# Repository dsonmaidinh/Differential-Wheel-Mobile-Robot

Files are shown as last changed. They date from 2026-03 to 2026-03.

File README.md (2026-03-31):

# DMRobot

Demo DMRobot

`DMRobot` là dự án điều khiển robot di động với mô hình **ESP32-S3 + STM32F103**, dùng **WebSocket/WiFi** để giao tiếp giữa app web và STM32 qua ESP32.

## Tổng quan

Dự án gồm hai phần chính:

- `firmware/esp`: firmware cho ESP32-S3 DevKitM-1 sử dụng PlatformIO và Arduino.
- `firmware/stm`: firmware cho STM32F103RCT6 với bộ xử lý điều khiển robot.

Ngoài ra, dự án còn có:

- `hardware/`: tài liệu PCB, sơ đồ mạch, file thiết kế board.
- `software/`: công cụ Python, GUI và script hỗ trợ kiểm tra/phân tích.
- `docs/`: ảnh và GIF minh họa app/robot.

## Tính năng chính

- Mô-đun ESP32-S3 làm gateway WiFi, chạy web server và WebSocket.
- Cầu nối UART giữa ESP32 và STM32 để gửi/nhận lệnh điều khiển.
- Hỗ trợ lệnh: `STOP`, `RUN`, `RETURN_HOME`, `SET_TRAJECTORY`, `SET_PATH`, `STATUS`.
- Giao tiếp JSON qua WebSocket để điều khiển và cấu hình từ app web.
- Chế độ WiFi AP với SSID mặc định `DMRobot_Net` và password `12345678`.
- Chế độ WiFi STA có thể cấu hình WiFi nhà sẵn trong `firmware/esp/src/main.cpp`.
- Giám sát trạng thái pin và trạng thái kết nối mạng.

## Giao diện

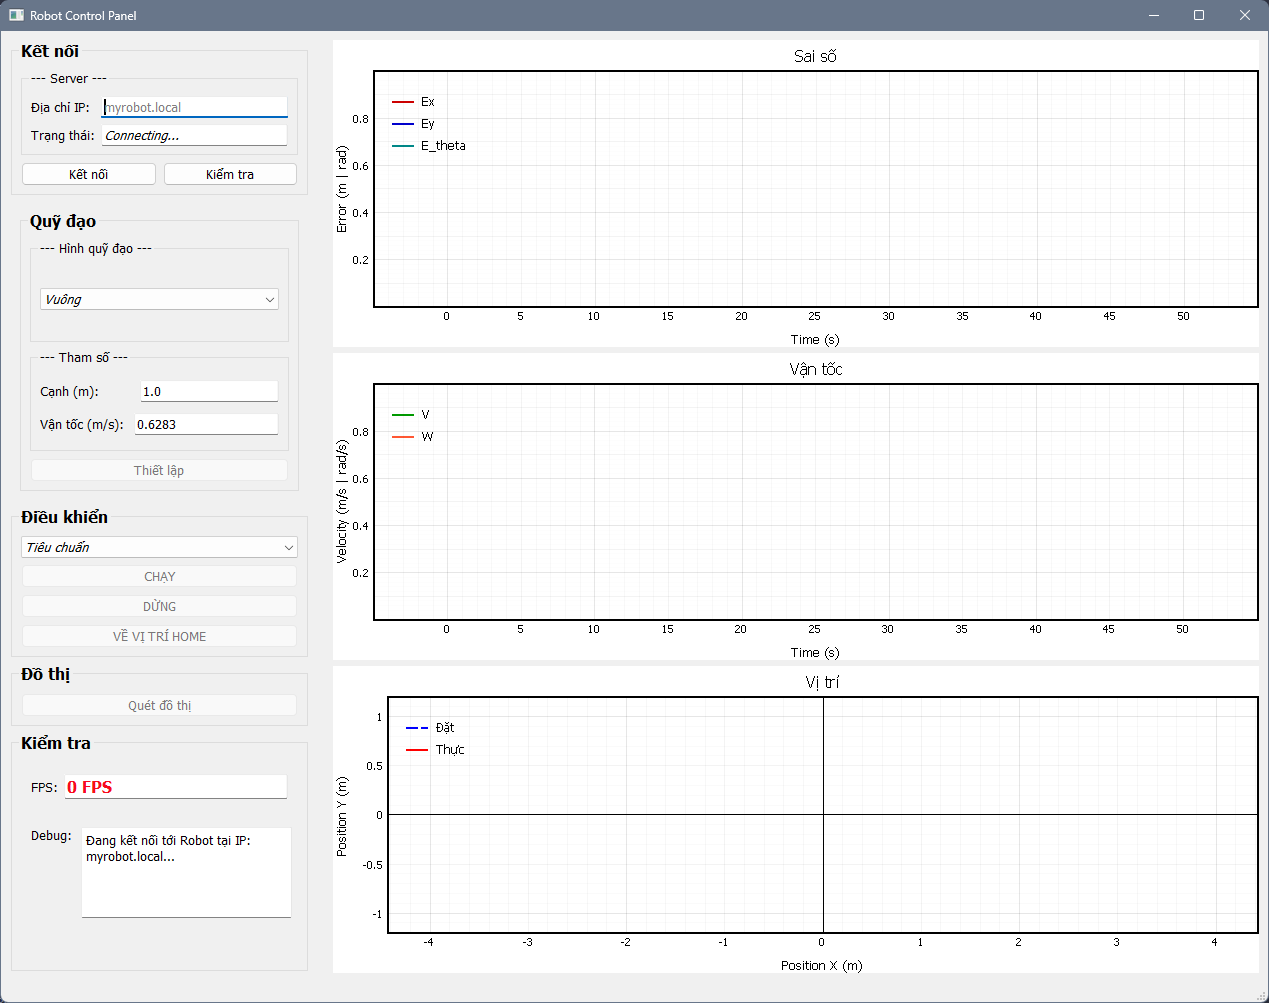
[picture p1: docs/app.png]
App DMRobot


## Cấu trúc thư mục

- `docs/`
  - `app.png`: ảnh giao diện ứng dụng.
  - `DMRobot.gif`: GIF demo.
- `firmware/esp/`
  - `platformio.ini`: cấu hình PlatformIO cho ESP32-S3.
  - `src/main.cpp`: mã nguồn chính điều khiển WiFi, WebSocket, UART.
- `firmware/stm/`
  - STM32F103 firmware và mã nguồn điều khiển robot.
- `hardware/`
  - Thiết kế PCB, sơ đồ, file xuất Gerber và các tài liệu phần cứng.
- `software/`
  - Script Python và phần mềm hỗ trợ.

## Cài đặt và chạy

1. Mở `firmware/esp` với PlatformIO.
2. Chọn environment: `esp32-s3-devkitm-1`.
3. Kết nối ESP32-S3 và build/upload firmware.
4. Mở Serial Monitor với tốc độ `115200`.
5. Kết nối WiFi tới `DMRobot_Net` hoặc cấu hình WiFi STA trong `firmware/esp/src/main.cpp`.
6. Truy cập trang web điều khiển hoặc `myrobot.local` nếu mDNS hoạt động.

## Tùy chỉnh

- Thay đổi SSID/AP và mật khẩu trong `firmware/esp/src/main.cpp`:
  - `ROBOT_WIFI_SSID`
  - `ROBOT_WIFI_PASSWORD`
  - `MY_WIFI_SSID`
  - `MY_WIFI_PASSWORD`
- Điều chỉnh tốc độ UART và chân RX/TX cho ESP32-S3 cũng nằm trong `firmware/esp/src/main.cpp`.

## Ghi chú

- ESP32-S3 kết nối tới STM32 qua UART trên chân `RX_PIN = 40` và `TX_PIN = 39`.
- Firmware STM32 nằm trong `firmware/stm` và cần STM32CubeIDE hoặc tool tương thích để build.

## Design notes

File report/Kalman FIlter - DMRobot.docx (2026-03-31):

# CHƯƠNG 1: Lý thuyết

## 1.1. Phương trình EKF Tổng quát và Giải phẫu thành phần

Một hệ thống tự hành luôn được mô tả bằng 2 phương trình phi tuyến cơ bản:

### 1.1.1. Phương trình chuyển trạng thái (Kinematic Model):

(Trạng thái hiện tại phụ thuộc vào trạng thái cũ, lệnh điều khiển, và nhiễu hệ thống).

### 1.1.2. Phương trình đo lường (Measurement Model):

(Giá trị cảm biến đo được phụ thuộc vào trạng thái thực tế và nhiễu cảm biến).

Giải phẫu các ma trận trong hệ thống:

- : Vector trạng thái (Kích thước ). Chứa thông tin ta cần tìm (VD: ).
- : Vector đầu vào (Kích thước ). Vận tốc từ Encoder.
- : Vector đo lường (Kích thước ). Giá trị đo từ IMU.
- : Hàm phi tuyến mô tả động học của robot (dùng để đoán vị trí tiếp theo).
- : Hàm phi tuyến mô tả mô hình cảm biến.

Các Ma trận Toán học sinh ra trong EKF:

- (Jacobian của ): Ma trận tuyến tính hóa hệ động học (Kích thước ).
- (Jacobian của ): Ma trận tuyến tính hóa hệ cảm biến (Kích thước ).
- : Ma trận hiệp phương sai trạng thái (Kích thước ). Thể hiện "độ mông lung, thiếu tự tin" của hệ thống về vị trí hiện tại. càng nhỏ, hệ thống càng tin chắc nó đang nằm đúng chỗ.
- : Ma trận nhiễu hệ thống (Kích thước ). Do trượt bánh xe, sai số mô hình cơ khí sinh ra.
- : Ma trận nhiễu đo lường (Kích thước ). Lấy từ Datasheet của IMU.
- : Độ lợi Kalman (Kalman Gain). Là trọng số quyết định EKF sẽ tin vào mô hình tính toán hay tin vào cảm biến thực tế ().

## 1.2. Hai vòng lặp thực thi EKF (Trái tim của thuật toán)

EKF hoạt động liên tục qua 2 bước: Predict (Nhắm mắt đi tiếp) và Update (Mở mắt nhìn cảm biến để sửa sai).

(Ký hiệu nghĩa là: Giá trị tại thời điểm , được dự đoán dựa trên dữ liệu của thời điểm ).

BƯỚC 1: DỰ ĐOÁN (PREDICT)

Trong bước này, EKF tạm thời bỏ qua IMU, chỉ dùng Encoder và các phương trình động học để đoán xem robot đi tới đâu.

1. Dự đoán trạng thái (Vị trí):

(Ý nghĩa: Vị trí mới = Vị trí cũ + Vận tốc x Thời gian).

2. Dự đoán sai số (Hiệp phương sai ):

(Ý nghĩa: Vì robot di chuyển mù mờ, sự "mông lung" () sẽ phình to ra cộng thêm nhiễu trượt bánh là ma trận chuyển vị của ).

BƯỚC 2: CẬP NHẬT (UPDATE)

Ngay khi IMU trả về dữ liệu mới (), EKF sẽ tính toán để bù trừ sai lệch.

3. Tính sai lệch đo lường (Innovation):

(Ý nghĩa: Sai lệch = Góc thực tế IMU đo được - Góc do hệ thống tự ảo tưởng dự đoán ra).

4. Tính hiệp phương sai của sai lệch:

(Ý nghĩa: Đánh giá xem tổng mức độ nhiễu của dự đoán () và nhiễu của con IMU () là bao nhiêu để chuẩn bị chia tỷ lệ).

5. Tính Độ lợi Kalman (Kalman Gain):

(Ý nghĩa: Nếu nhiễu IMU () nhỏ → lớn → lớn → Tin IMU. Nếu IMU nhiễu quá → nhỏ → Tin vào dự đoán của Encoder).

6. Cập nhật Trạng thái chuẩn xác cuối cùng (Vị trí thật):

(Ý nghĩa: Vị trí thật = Vị trí dự đoán + (Độ lợi x Sai lệch). Đây chính là tọa độ cực mượt mà cậu sẽ xuất ra màn hình Python).

7. Cập nhật lại Ma trận sai số cho vòng lặp sau:

(Ý nghĩa: Sau khi dùng IMU để sửa sai, hệ thống tự tin hơn, sự "mông lung" () sẽ thu hẹp lại. là ma trận đơn vị).

# CHƯƠNG 2: Áp dụng

## 2.1. Xác các giá trị ban đầu

Robot của cậu là dạng Differential Drive (Vi sai), di chuyển trên mặt phẳng 2D.

- Vector Trạng thái (3x1): Đây là những gì ta cần EKF ước lượng và xuất ra để vẽ quỹ đạo.

(Trong code, nó chính là me->Px, me->Py, kinematics.actual.theta).

- Vector Đầu vào (2x1): Lấy từ hàm đọc Encoder (đã qua lọc nhiễu).

(Trong code, nó chính là biến v và w tính từ motor_omega_r và motor_omega_l).

- Vector Đo lường (1x1): Lấy từ IMU ICM-42688.

## 2.2. EKF

### 2.2.1. Dự đoán trạng thái

### 2.2.2. Cập nhật

#### 2.2.2.1. Phương trình tính sai số đo lường :

- Công thức:
- Xác định vector:
- Xác định
- Kết luận:

#### 2.2.2.2. Phương trình tính Độ lợi Kalman

- Công thức:
- Ma trận Jacobi :
- Ma trận chuyển vị :
- Ma trận hiệp phương sai :
- Ma trận hiệp phương sai ban đầu :

Lúc mới bật nguồn, robot không biết mình ở đâu, cứ gán là một ma trận đường chéo với số nhỏ (tự tin ban đầu).

- Ma trận :
- Ma trận
- Ma trận nhiễu quá trình :

Thể hiện độ trượt bánh, sai số encoder. Thường sẽ nhiễu ít hơn (vì tích phân từ sự chênh lệch 2 bánh, rất dễ sai).

Cách 1: xác định bằng công thức

Hướng 1 - Từ nhiễu encoder

Gọi là phương sai nhiễu do encoder. Lan truyền nhiễu qua mô hình động học:

Sau đó lan truyền vào không gian trạng thái:

Cách 2: cho đại

(Tuning: Nếu robot đi thực tế bị trượt bánh nhiều, hãy tăng các số trong lên).

- Phương trình tính hiệp phương sai của sai số đo lường:

Ma trận nhiễu đo lường

(Nếu thấy EKF tin IMU mù quáng quá làm tọa độ giật giật, hãy tăng R lên 0.05 hoặc 0.1).

- Cập nhật lại Ma trận sai số cho vòng lặp sau:

## 2.3. MẸO TỐI ƯU CỰC ĐỈNH CHO C CODE (Không cần thư viện Ma trận)

Hầu hết mọi người khi lập trình EKF đều nhét thư viện ma trận cồng kềnh (như Eigen trên C++ hoặc CMSIS-DSP trên C) vào. Nhưng hệ thống của cậu chỉ là 3x3 và 1x3, nếu ta giải tay các phép nhân ma trận ra phương trình đại số, code C của cậu sẽ chạy nhanh gấp 100 lần và tốn chưa tới 1KB RAM!

Tớ đã giải sẵn hệ phương trình ma trận ở Bước Update cho cậu. Hãy nhìn sự kỳ diệu của toán học khi ma trận làm mọi thứ triệt tiêu đi:

Gọi Ma trận là:

1. Tính sai lệch ():

(Nhớ Normalize góc về )

2. Tính hiệp phương sai sai lệch ():

Phép nhân tưởng phức tạp, thực chất giải tay ra chỉ còn:

3. Tính Kalman Gain ():

Phép nhân giải tay ra một vector 3x1 cực kỳ đơn giản:

4. Cập nhật vị trí thực tế ():

(Cậu thấy chưa? và được bù trừ lỗi trực tiếp dựa vào sai lệch góc nhân với hệ số chéo sinh ra từ hiệp phương sai!)

5. Cập nhật lại Ma trận :

→ Kết luận lộ trình Code:

Với việc giải tay này, trong file mw_kinematics.c, cậu chỉ cần khai báo một mảng 2 chiều float P[3][3].

Mỗi chu kỳ 10ms:

1. Tính dự đoán (Đã có sẵn trong hàm mw_kinematics_forward).
2. Viết thêm vài dòng lệnh cập nhật P[3][3] theo ma trận Jacobian .
3. Đọc IMU, tính bằng đúng 5 dòng lệnh nhân chia cơ bản.
4. Cộng dồn vào là xong!

# CÂU HỎI:

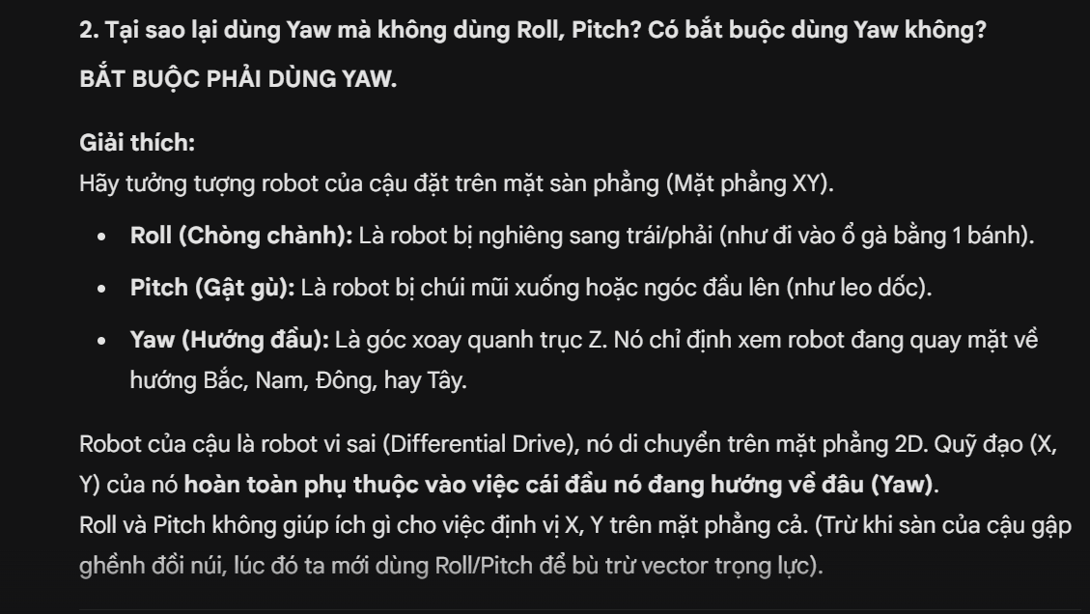
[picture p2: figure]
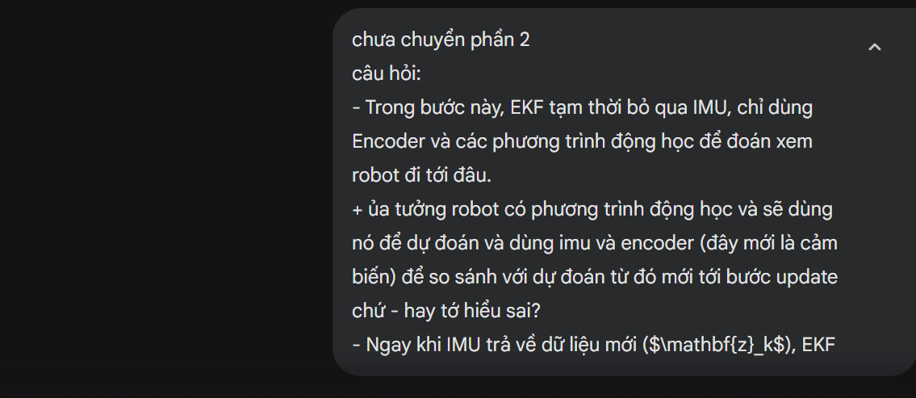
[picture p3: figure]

## 2.6. và ở đâu sao không thấy đề cập?

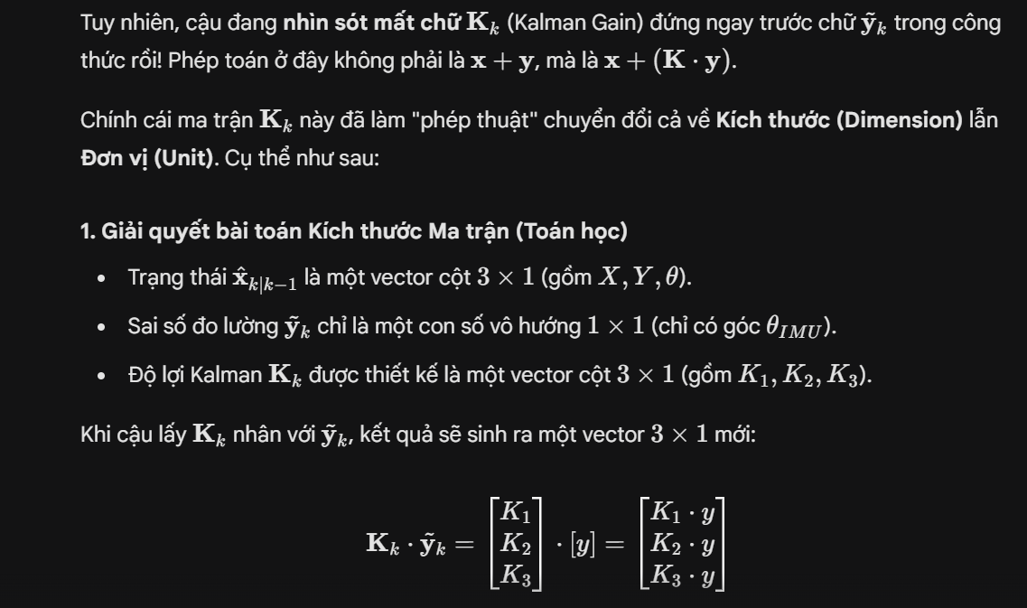
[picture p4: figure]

- dùng matlab để cho ra phương trình cuối cùng → giảm khối lượng tính toán cho vi điều khiển để cuối cùng các phép tính chỉ là thế số mà mcu đọc từ các nguồn thôi chứ k cần nhân cộng, chuyển vị, nghịch đảo ma trận nữa

- nếu thực tế ta fusion nhiều cảm biến hoặc muốn lọc nhiều data hơn→các ma trận cũng sẽ lớn lên → cũng dùng matlab để cho ra phương trình cuối cùng rồi viết vào vi điều khiển hay là sẽ có giới hạn số lượng của vector trạng thái x

- các ma trận R, Q, F đâu phải là hằng số đâu đúng không mà là ta tự ước tính --> có cách nào để tìm nếu nó không phải hằng số không?

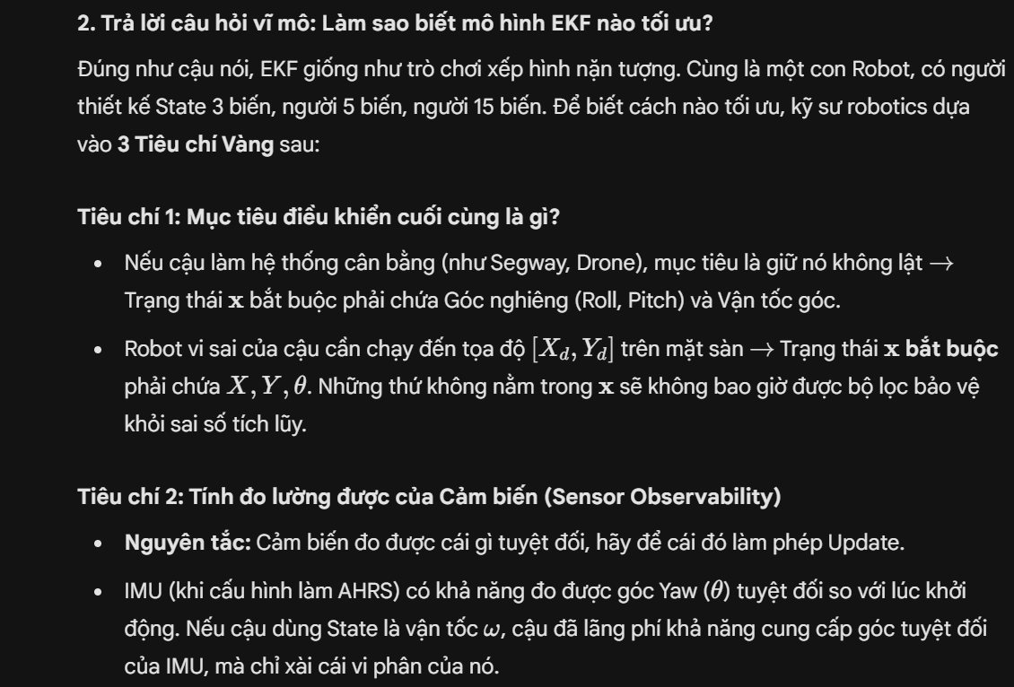
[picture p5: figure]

# UPDATE

- Động cơ
  - Chuyển cách tính vị trí sang Odometry: cho xe chạy 1 đoạn để so sánh độ chính xác với công thức tính vị trí dùng nguyên hàm vận tốc
  - Hiệu chuẩn động học cơ khí (Kinematic Calibration). Cụ thể là tìm hiểu phương pháp UMBmark
  - Sử dụng bộ điều khiển PID + Fuzzy cho động cơ
- IMU
  - Cách tính yaw không bị nhiễu - ổn định
- EKF
  - thêm bias vào state
  - Kiểm chứng bộ lọc EKF - nâng lên thành AEKF
  - Bổ sung thêm phần tử v và w vào vector trạng thái x (tùy chọn)
- Báo cáo
  - Trình bày cách tính vị trí - thêm hình
  - Sửa hình 3.2
    - Bộ tạo quỹ đạo
    - WL → WL_pr
  - Bỏ các khối matlab vì không có mô phỏng
  - Sửa EKF
    - Sửa công thức + thứ tự tính toán
    - Giải thích chi tiết từng bước
      - Tính ước lượng
      - Lan truyền
      - Cập nhật

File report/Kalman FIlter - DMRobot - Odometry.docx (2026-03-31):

## 1.1. Xác các giá trị ban đầu

Vector trạng thái

Vector đầu vào

Trong đó

| tính từ trung bình 1000 mẫu khi cho imu đứng yên hoặc tính từ datasheet

Vector đo lường

- Đang chạy

- Đứng yên

Ma trận F:

Ma trận P:

Ma trận Q:

Ma trận R:

- Đang chạy

- Đứng yên

Ma trận H:

- Đang chạy

- Đứng yên

## 1.2. EKF

### 1.2.1. Dự đoán

Vector trạng thái:

Ma trận hiệp phương sai:

### 1.2.2. Cập nhật

Cập nhật Kalman Gain:

Cập nhật vector trạng thái:

Cập nhật ma trận P:

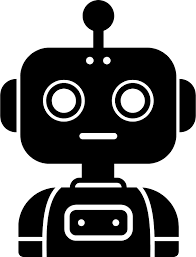
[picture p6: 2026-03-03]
hardware/v1/robot.png

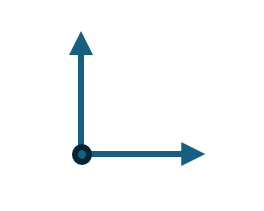
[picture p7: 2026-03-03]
hardware/v1/axis.png

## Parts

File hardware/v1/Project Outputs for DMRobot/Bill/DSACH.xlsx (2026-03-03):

Comment | Description | Designator | Footprint | LibRef | Quantity | Giá | Giá tổng | Chỗ mua khác | Có sẵn
Nut Nhan 2 Chan SMD 3x6x2.5 | Nut Nhan 2 Chan SMD 3x6x2.5 | BOOT, EN, RST | Nut Nhan 2 Chan SMD 3x6x2.5 | Nut Nhan 2 Chan SMD 3x6x2.5 | 3 | 2500 | 2500
cong tac bap benh |  | BT1 | CONG TAC BAP BENH | cong tac bap benh | 1 | 4000 | 4000
104 | Dán | C1, C6, C8, C10, C16, C17, C20, C22, C23, C25, C26, C27, C28, C29, C30, C33, C35 | tu 0805 | Tu 0805 104 50V 10% | 17 | 3800 | 3800
22uf | Dán | C2 | tu 0805 | Tu 0805 222 50V 10% | 1 | 1600 | 1600
100uF | Dán | C3 | tu tantalum smd7343 | Tu tantalum 100uF 50V SMD7343 | 1 | 10000 | 20000
100uF | Dán | C4, C5 | tu nhom 6.3 (d) | Tu Nhom 100uF 25V | 2 | 6000 | 6000
103 | Dán | C7 | tu 0805 | Tu 0805 104 50V 10% | 1 | 3800 | 3800
106 | Dán | C9, C18, C19, C21 | tu 0805 | Tu 0805 106 16V 10% | 4 | 2000 | 5000
105 | Dán | C11 | tu 0805 | Tu 0805 105 50V 10% | 1 | 8000 | 7000
102 | Dán | C12 | tu 0805 | Tu 0805 102 50V 10% | 1 | 6000 | 6000
332 | Dán | C13 | tu 0805 | Tu 0805 332 50V 10% | 1 | 3800 | 3800
226 | Dán | C14, C15 | tu 1206 | Tu 1206 226 16V 20% | 2 | 7600 | 7600
22uF | Dán | C24, C34 | tu nhom 6.3 (D) | Tu Nhom 22uF 25V | 2 | 3500 | 4800
10pF | Dán | C31, C32 | tu 0805 | Tu 0805 10pF 50V 10% | 2 | 5000 | 5000
BZT52H-C3V3 | Zener Diode | D1 | SOD123 | Diode Zener | 1 | 6000 | 4000
ZENER 3.3V | Zener Diode | D2 | SOD123 | Diode Zener | 1 | 6000
SS34 | Dán | D3 | DIODE SMA | Diode SS34 ( 1N5822 ) | 1 | 2000 | 5000
LI0805H121R-10 | EMI Ferrite Chip Bead, 0805, 800MA, 120Ohms @100MHz, DCR Max 0.150Ohm | Laird Performance Materials LI0805H121R-10 | E1 | FB_LI0805H121R-10 | LI0805H121R-10 | 1 | 8000 | 8000
ENCODER | Cắm | ENC1, ENC2 | XH2.54M-4 | Header 4P 2.54 Duc Thang | 2
ESP32-S3-WROOM-1-N4 |  | ESP | XCVR_ESP32-S3-WROOM-1-N4 | ESP32-S3-WROOM-1-N4 | 1
LOADER ESSP32 | Cắm | ESP_FLASH | XH2.54M-4 | Header 4P 2.54 Duc Thang | 1
2A 24V | 2A 24V SMD1812 | F1 | Cau chi tu phuc hoi 2A 24V SMD1812 | Cau chi tu phuc hoi 2A 24V SMD1812 | 1 | 3000 | 6000
MOD MPU_6050 |  | I1 | MOD MPU-6050 | MOD MPU_6050 | 1
TYPE-C-31-M-12 | USB Connectors 24 Receptacle 1 8.94*7.3mm RoHS | J1 | HRO_TYPE-C-31-M-12 | TYPE-C-31-M-12 | 1 | 1500 | 3000
JACK DC 5.5 | JACK DC 5.5 | JACK DC1 | JACK DC 5.5 | JACK DC 5.5 | 1 | 4000
100uH - 3A SMD | Dán | L1 | Cuon Cam 12x12x10 | CUON CAM 100uH SMD | 1 | 2800 | 5600 | icdayroi
LED 0805 | Dán | L2, L3 | LED-0805-Red | LED 0805 Do | 2 | 2300 | 2300
LED 0805 | Dán | L4 | LED-0805-Green | LED 0805 Xanh La | 1 | 2300 | 2300
LED 0805 | Dán | L5 | LED-0805-Yellow | LED 0805 Vang | 1 | 2500 | 2500
MOTOR | Cắm | M1, M2 | XH2.54M-2 | Header 2P 2.54 Duc Thang | 2 | 5600 | 3800
IRF4905STRLPBF | Mosfet P | Q1 | TO-263 (D2PAK) | Mosfet P | 1 | 24000 | 48000
SS8050-G | NPN TRANSISTOR 1.5A 40V SOT-23 R | Q2, Q3 | FP-SS8050-G-MFG | CMP-20235-000001-1 | 2 | 3000 | 6000
47k | Dán | R1 | tro smd 0603 | Tro 0603 5% 47k | 1 | 1600 | 2500
100k | Dán | R2, R4 | tro smd 0805 | Tro 0805 5% 100k | 2 | 2500 | 2500
10k | Dán | R3, R5, R10, R11, R12, R21, R22, R23, R29 | tro smd 0805 | Tro 0805 5% 10k | 9 | 2500 | 2500
22k | Dán | R6 | tro smd 0805 | Tro 0805 5% 22k | 1 | 2800 | 2500
220 | Dán | R7 | tro smd 0805 | Tro 0805 5% 220R | 1 | 2500 | 2500
3.9k | Dán | R8 | Tro SMD 0805 | Tro 0805 5% 3.9k | 1 | 2800 | 2500
6.8k | Dán | R9 | tro smd 0805 | Tro 0805 5% 6.8k | 1 | 2500 | 2500
2.2k | Dán | R13, R14, R15 | tro smd 0805 | Tro 0805 5% 2.2k | 3 | 2500 | 2500
0R | Dán | R16, R17, R24, R25, R26, R27 | tro smd 0805 | Tro 0805 5% 0R | 6 | 2800 | 2800
5.1k | Dán | R18, R19 | tro smd 0805 | Tro 0805 1% 5.1k | 2 | 2500 | 2500
30k | Dán | R20, R28 | tro smd 0805 | Tro 0805 5% 30k | 2 | 2800 | 2500
STM32F100xx_LQFP64 |  | STM | STM32_LQFP64 | STM32F100xx_LQFP64 | 1 | 46000 | 46000
Header 4P 2.54 Duc Thang | Cắm | STM_FLASH | XH2.54M-4 | Header 4P 2.54 Duc Thang | 1 | 5500 | 7400
MP2307DN-HW-LF-P | 3A 23V 340KHz Synchronous Rectified Step-Down Converter | U1 | IC8_MP2307_MNP | MP2307DN-HW-LF-P | 1 | 13000 | 26000
DRV8871DDARQ1 | Unipolar Motor Driver NMOS PWM 8-SO PowerPad | U2, U4 | SOIC8_50_328_25X90_SMT | IC_DRV8871DDARQ1 | 2 | 90000 | 90000 | shopee
CH340C | USB Bridge, USB to UART USB 2.0 UART Interface | U3 | SOIC16_50_284_25X90_SMT | IC_CH340C | 1 | 13000 | 26000
8Mhz | Crystal SMD 24MHz 10PPM 7pF 3225 | X1 | XTAL_3225 | TSX-3225_24.0000MF15X-AC | 1 | 4000 | 8000
oled |  |  |  |  |  |  | 72000
GA25-370 Encoder Động Cơ Giảm Tốc 130rpm |  |  |  |  |  |  | 164000
mạch in |  |  |  |  |  |  | 100000
 |  |  |  |  |  |  | 744600

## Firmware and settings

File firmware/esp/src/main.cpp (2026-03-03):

#include <Arduino.h>
#include <WiFi.h>
#include <ESPAsyncWebServer.h>
#include <ArduinoJson.h>
#include <ESPmDNS.h>

// =================================================================================
// PHẦN CẤU HÌNH HỆ THỐNG (USER CONFIGURATION)
// =================================================================================
// CẤU HÌNH PHẦN CỨNG (HARDWARE)
#define CPU_FREQ_MHZ            240         // Ép xung CPU (MHz)
#define STM32Serial             Serial2     // Cổng Serial kết nối STM32
#define UART_RX_PIN             40          // Chân RX
#define UART_TX_PIN             39          // Chân TX
#define BATTERY_PIN             3
#define STM32_BAUDRATE          225000      // Tốc độ giao tiếp với STM32 (High Speed)
#define STM32_SEND_INTERVAL_MS  40          // Chu kỳ gửi lệnh xuống STM32 (ms)
#define DEBUG_BAUDRATE          115200      // Tốc độ Serial Debug (USB)

// CẤU HÌNH WIFI & SERVER (NETWORK)
#define ROBOT_WIFI_SSID               "DMRobot_Net" // Tên WiFi Robot (chế độ AP)
#define ROBOT_WIFI_PASSWORD           "12345678"    // Mật khẩu WiFi Robot (chế độ AP)
#define MY_WIFI_SSID                  "DONG SON"    // Tên WiFi nhà (chế độ STA)
#define MY_WIFI_PASSWORD              "05041901"    // Mật khẩu WiFi nhà (chế độ STA)
#define MY_HOSTNAME                   "myrobot"     // Tên mDNS (chế độ STA)
#define WS_PORT                       80            // Cổng WebSocket
#define WS_PATH                       "/ws"         // Đường dẫn WebSocket
#define WS_SEND_INTERVAL_MS           80          

// CẤU HÌNH GIAO THỨC (PROTOCOL DEFINITIONS)
#define PROTOCOL_BATCH_HEADER_1       0xAA          // Header gói Batch từ STM32
#define PROTOCOL_BATCH_HEADER_2       0x55          // Header gói Batch từ STM32
#define PROTOCOL_BATCH_FOOTER         0xEE          // Footer gói Batch từ STM32
#define PROTOCOL_CMD_HEADER_1         0xAA          // Header lệnh gửi xuống STM32
#define PROTOCOL_CMD_HEADER_2         0xBB          // Header lệnh gửi xuống STM32
#define PROTOCOL_CHECKSUM             0xCC          // Byte checksum lệnh gửi xuống 

#define PROTOCOL_MAP_HEADER_1         0xAA          // Header lệnh gửi xuống STM32
#define PROTOCOL_MAP_HEADER_2         0xBB          // Header lệnh gửi xuống STM32

// CẤU HÌNH KÍCH THƯỚC DỮ LIỆU (DATA SIZING)
#define SAMPLES_PER_BATCH       4           // Số mẫu trong 1 gói Batch (Quan trọng)
#define TX_BUFFER_SIZE          32          // Kích thước buffer gửi lệnh xuống STM32
#define UART_RX_BUFFER_SIZE     8192        // Kích thước Buffer nhận phần cứng UART (ESP32 - có thể để lớn)
// 
#define DebugCode false                      // [TRUE]: Bật in Debug, [FALSE]: Tắt toàn bộ để tối ưu
#define MY_WIFI   true                      // [TRUE]: Kết nối WiFi nhà (STA), [FALSE]: Tự phát WiFi (AP)

// ==========================================
// ĐỊNH NGHĨA STRUCT & BATCH SIZE
// ==========================================
#pragma pack(push, 1)

// Struct dữ liệu 1 mẫu (9 float * 1 float (4 bytes) = 36 bytes)
typedef struct { 
    float Pdx, Pdy, Px, Py, V, W, Ex, Ey, Etheta; 
} DMAData_t;

// Struct Batch nhận từ STM32 (Header + n mẫu + Footer)
typedef struct { 
    uint8_t batch_header[2]; 
    DMAData_t samples[SAMPLES_PER_BATCH]; 
    uint8_t batch_footer; 
} RxBatchData_t;

// Struct lệnh ngắn (4 bytes)
typedef struct {
    uint8_t header[2]; 
    uint8_t cmd;       
    uint8_t checksum;  
} TxCMDData_t;

// Struct cấu hình (13 bytes)
typedef struct {
    uint8_t header[2]; 
    uint8_t cmd;       
    uint8_t shape;
    float param;
    float vel;
    uint8_t checksum;  
} TxConfigData_t;

typedef struct {
    uint8_t header[2];
    uint8_t cmd;
    uint8_t wifi_status;
    uint8_t battery_status;
    uint8_t checksum;
} TxStatusData_t;

typedef union {
    uint8_t raw[TX_BUFFER_SIZE];// Đệm đủ cho Queue
    TxCMDData_t cmdFrame;       // Gói lệnh ngắn (4 byte)
    TxConfigData_t configFrame; // Gói cấu hình (13 byte)
    TxStatusData_t statusFrame;
} TxPacket_t;

#pragma pack(pop)

// ==========================================
// BIẾN TOÀN CỤC & QUEUE
// ==========================================
AsyncWebServer server(WS_PORT);
AsyncWebSocket ws(WS_PATH);

// --- QUEUES & SYNC ---
QueueHandle_t rxQueue;          // UART → WebSocket
QueueHandle_t txQueue;          // WebSocket → UART (MỚI!)
SemaphoreHandle_t wifiMutex;    // Khóa truy cập WiFi

TxCMDData_t txCMDBuffer;
TxConfigData_t txConfigBuffer;

#if DebugCode
    // --- STATS ---
    volatile uint32_t uart_rx_count = 0;
    volatile uint32_t uart_tx_count = 0;
    volatile uint32_t ws_sent_count = 0;
    volatile uint32_t queue_drops = 0;
    volatile uint32_t ws_blocked = 0;
#endif
volatile bool isRun = true;      // Chờ app gửi lệnh mới bắt đầu đọc UART
size_t rxDataSize = sizeof(RxBatchData_t);

// --- ENUMS ---
typedef enum { CMD_STOP, CMD_RUN, CMD_RETURN_HOME, CMD_SET_TRAJECTORY, CMD_SET_PATH, CMD_STATUS } RobotCommand_t;
typedef enum { CIRCLE, SQUARE, TRIANGLE } RobotShape_t;
// Thêm vào sau các Enum có sẵn
typedef enum {
    WIFI_STATUS_CONNECTING = 0x00,
    WIFI_STATUS_CONNECTED  = 0x01,
} WifiStatus_t;

typedef enum {
    BATTERY_STATUS_100 = 0x00,
    BATTERY_STATUS_60  = 0x01,
    BATTERY_STATUS_50  = 0x02,
} BatteryStatus_t;
typedef enum {
    BAT_TYPE_2S = 0,
    BAT_TYPE_3S = 1
} BatteryType_t;
#define MY_BATTERY_TYPE    BAT_TYPE_3S
// Biến lưu trạng thái hiện tại để gửi
volatile uint8_t current_wifi_stat = WIFI_STATUS_CONNECTING;
volatile uint8_t current_bat_stat  = BATTERY_STATUS_100;

// Macro debug cho gọn
#if DebugCode
    #define DBG(...) Serial.printf(__VA_ARGS__)
    #define DBG_LN(...) Serial.println(__VA_ARGS__)
#endif

void SendStatusToSTM32();
void WiFiEvent(WiFiEvent_t event);

// ================================================================
// WEBSOCKET HANDLER - GỬI VÀO QUEUE THAY VÌ GỬI TRỰC TIẾP
// ================================================================
static inline uint8_t CalculateChecksum(uint8_t *pData, uint16_t len) {
    uint8_t sum = 0;
    for (uint16_t i = 0; i < len; i++) {
        sum += pData[i];
    }
    return sum;
}
void handleWebSocketMessage(void *arg, uint8_t *data, size_t len) {
    AwsFrameInfo *info = (AwsFrameInfo*)arg; 

    // [SỬA ĐỔI 1] Bỏ điều kiện info->opcode == WS_TEXT ở đây
    // Để chấp nhận cả WS_TEXT và WS_BINARY
    if (!(info->final && info->index == 0 && info->len == len)) return;

    // ============================================================
    // TRƯỜNG HỢP 1: DỮ LIỆU VĂN BẢN (JSON COMMANDS)
    // ============================================================
    if (info->opcode == WS_TEXT) {
        data[len] = 0; 
        JsonDocument doc;
        if (deserializeJson(doc, (char*)data) != DeserializationError::Ok) return;

        int cmd = doc["cmd"];
        
        TxPacket_t txPacket; 
        memset(txPacket.raw, 0, sizeof(txPacket.raw));

        switch(cmd) {
            case CMD_STOP:
                txPacket.cmdFrame.header[0] = PROTOCOL_CMD_HEADER_1;
                txPacket.cmdFrame.header[1] = PROTOCOL_CMD_HEADER_2;
                txPacket.cmdFrame.cmd = (uint8_t)cmd;
                txPacket.cmdFrame.checksum = CalculateChecksum(txPacket.raw, offsetof(TxCMDData_t, checksum));  

                xQueueSend(txQueue, &txPacket, 0); 
                isRun = false;                    
                break;

            case CMD_RUN:
            case CMD_RETURN_HOME:
                txPacket.cmdFrame.header[0] = PROTOCOL_CMD_HEADER_1;
                txPacket.cmdFrame.header[1] = PROTOCOL_CMD_HEADER_2;
                txPacket.cmdFrame.cmd = (uint8_t)cmd;
                txPacket.cmdFrame.checksum = CalculateChecksum(txPacket.raw, offsetof(TxCMDData_t, checksum));

                xQueueSend(txQueue, &txPacket, 0);
                isRun = true;
                break;
                
            case CMD_SET_TRAJECTORY:
                txPacket.configFrame.header[0] = PROTOCOL_CMD_HEADER_1;
                txPacket.configFrame.header[1] = PROTOCOL_CMD_HEADER_2;
                txPacket.configFrame.cmd = CMD_SET_TRAJECTORY;
                txPacket.configFrame.shape = doc["Shape"].is<int>() ? (uint8_t)doc["Shape"] : SQUARE;
                txPacket.configFrame.param = doc["Para"].is<float>() ? doc["Para"] : 0.0f;
                txPacket.configFrame.vel = doc["Vel"].is<float>() ? doc["Vel"] : 0.0f;
                txPacket.configFrame.checksum = CalculateChecksum(txPacket.raw, offsetof(TxConfigData_t, checksum));

                xQueueSend(txQueue, &txPacket, 0);
                
                #if DebugCode
                    DBG_LN("📲 App Config Trajectory -> Queue");
                #endif
                break;
        }
    }

    // ============================================================
    // TRƯỜNG HỢP 2: DỮ LIỆU NHỊ PHÂN (PATH DATA - CMD_SET_PATH)
    // ============================================================
    else if (info->opcode == WS_BINARY) {
        // Kiểm tra sơ bộ Header để chắc chắn là gói tin của mình (AA 55)
        // Header 1 (Byte 0) và Header 2 (Byte 1)
        if (len > 2 && data[0] == PROTOCOL_MAP_HEADER_1 && data[1] == PROTOCOL_MAP_HEADER_2) {
            
            // [PHƯƠNG ÁN PASS-THROUGH]
            // Gửi thẳng xuống STM32 qua UART ngay lập tức
            // Không dùng Queue vì gói tin này rất lớn (> 100 byte), Queue TxPacket_t không chứa nổi
            Serial2.write(data, len);

            #if DebugCode
                DBG("📦 Received Binary Path! Size: ");
                DBG_LN(len);
                DBG_LN("--> Forwarded directly to STM32 via UART2");
            #endif
        }
    }
}

void onEvent(AsyncWebSocket *server, AsyncWebSocketClient *client, 
             AwsEventType type, void *arg, uint8_t *data, size_t len) {
    switch(type) {
        case WS_EVT_CONNECT:
            #if DebugCode
                DBG("✅ Client #%u connected\n", client->id());
            #endif
            if (client->client()) {
                client->client()->setNoDelay(true);
            }
            break;
        case WS_EVT_DISCONNECT:
            #if DebugCode
                DBG("❌ Client #%u disconnected\n", client->id());
            #endif
            break;
        case WS_EVT_DATA:
            handleWebSocketMessage(arg, data, len);
            break;
        default:
            break;
    }
}

// ================================================================
// TASK 1: ĐỌC UART (CORE 1) - THÊM THROTTLING
// ================================================================
void TaskUARTReceiver(void *pvParameters) {
    RxBatchData_t batchBuffer;
    #if DebugCode
        static uint32_t rxDataCount = 0;
        static uint32_t last_receive_time = 0;
        static uint32_t sync_count = 0;
        static uint32_t check_uart_task_count = 0;
        static uint32_t last_check_uart_task_time = 0;
        DBG_LN("📡 UART RX Task started (Core 1)");
    #endif

    uint8_t head[2];
    
    STM32Serial.setTimeout(20); // Giảm timeout xuống thấp hơn nữa để phản ứng nhanh

    while (1) {
        // --- PHẦN 1: KEEP ALIVE LOG ---
        #if DebugCode
            if(millis() - last_check_uart_task_time >= 2000){
                DBG("🧐 UART RX Task is alive - Count: %lu\n", ++check_uart_task_count);
                last_check_uart_task_time = millis();
            }
        #endif
        
        if (!isRun) {
            // [FIX LỖI] Xả sạch buffer để khi chạy lại không dính dữ liệu cũ
            while(STM32Serial.available()) {
                STM32Serial.read();
            }
            vTaskDelay(100 / portTICK_PERIOD_MS); // Ngủ sâu để tiết kiệm CPU
            continue; // Quay lại đầu vòng lặp
        }
        // --- PHẦN 2: LOGIC ĐỌC DỮ LIỆU ---
        // [FIX 1] Bỏ điều kiện kiểm tra thời gian (millis - last >= INTERVAL).
        // Lý do: Có dữ liệu là phải múc ngay, không chờ đủ giờ mới múc -> gây đầy buffer.
        if (STM32Serial.available() >= sizeof(RxBatchData_t)) {
            
            // Peek: Xem trộm byte đầu tiên xem có phải AA không
            if (STM32Serial.peek() == PROTOCOL_BATCH_HEADER_1) {
                // Đọc thử 2 byte Header
                STM32Serial.readBytes(head, 2);

                if (head[1] == PROTOCOL_BATCH_HEADER_2) {
                    // Header chuẩn (AA 55) -> Đọc phần thân
                    uint8_t* ptr = (uint8_t*)&batchBuffer;
                    
                    // Gán lại header vào struct để tí nữa tính checksum hoặc gửi đi
                    batchBuffer.batch_header[0] = PROTOCOL_BATCH_HEADER_1;
                    batchBuffer.batch_header[1] = PROTOCOL_BATCH_HEADER_2;

                    size_t bytesToRead = sizeof(RxBatchData_t) - 2;
                    size_t count = STM32Serial.readBytes(ptr + 2, bytesToRead);

                    // [FIX 2] Kiểm tra Footer 
                    if (count == bytesToRead && batchBuffer.batch_footer == PROTOCOL_BATCH_FOOTER) {
                        
                        // [FIX 3 - QUAN TRỌNG] Thêm Checksum để chống nhiễu khi nạp code
                        // (Giả sử byte cuối cùng của samples là checksum hoặc footer đóng vai trò check)
                        // Nếu cậu không có checksum thì Footer 0xEE là chốt chặn cuối cùng.
                        #if DebugCode
                            uart_rx_count++;
                        #endif
                        
                        #if DebugCode 
                            // Chỉ log khi nhận thành công
                            DBG("Đã nhận: %d Batch | dt: %lu ms\n", ++rxDataCount, millis() - last_receive_time);
                            last_receive_time = millis();
                        #endif

                        // Đẩy vào Queue
                        if (uxQueueSpacesAvailable(rxQueue) == 0) { // nếu đầy thì bỏ qua
                            RxBatchData_t dummy;
                            xQueueReceive(rxQueue, &dummy, 0); 
                            #if DebugCode
                                queue_drops++;
                            #endif
                        }
                        xQueueSend(rxQueue, &batchBuffer, 0);
                        
                    } else {                        
                        #if DebugCode 
                            DBG("⚠️ Lỗi Footer/Size (Count: %d, Exp: %d, Footer: %02X) -> Skip packet\n", 
                                count, bytesToRead, batchBuffer.batch_footer);
                            sync_count++;
                        #endif
                        
                        // Tùy chọn: Xả nhẹ 1 byte để tránh lặp vô hạn nếu kẹt đúng byte AA giả
                        // Nhưng thường logic 'else' ở dưới cùng sẽ lo việc này.
                    }
                } else {
                    // Header 1 là AA, nhưng Header 2 không phải 55
                    // Đã đọc 2 byte ra rồi -> Coi như bỏ qua gói rác này.
                    #if DebugCode 
                        DBG("⚠️ Header 2 sai: %02X -> Skip\n", head[1]);
                    #endif
                }
            } else {
                // Byte đầu tiên không phải AA -> Đọc bỏ 1 byte để dịch cửa sổ tìm kiếm
                STM32Serial.read(); 
                #if DebugCode 
                   DBG("Rác: Bỏ qua 1 byte\n"); // Comment lại cho đỡ spam log
                #endif
            }
            continue;
        }
        else {
            vTaskDelay(1); // Yield cực ngắn
        }
    }
}

// ================================================================
// TASK 2: GỬI WEBSOCKET (CORE 0) - KHÔNG BLOCK
// ================================================================
// CODE TEST STRESS WIFI (Không dùng Queue từ UART)
void TaskWebSocketSender(void *pvParameters) {
    RxBatchData_t dataToSend;
    #if DebugCode
        DBG_LN("📤 WebSocket Sender: Real Mode (Queue -> WiFi)");
    #endif

    while (1) {
        // Chờ dữ liệu từ Queue (Block tối đa 50ms)
        // Nếu STM32 gửi chuẩn, Queue sẽ có dữ liệu đều đặn mỗi 50ms (do UART gom 25 mẫu * 2ms)
        if (xQueueReceive(rxQueue, &dataToSend, pdMS_TO_TICKS(STM32_SEND_INTERVAL_MS)) == pdTRUE) {
            
            if (ws.count() > 0) {
                // Kiểm tra xem socket có đang bận không
                if (ws.availableForWriteAll()) {
                    ws.binaryAll((uint8_t*)&dataToSend, sizeof(RxBatchData_t));
                    #if DebugCode
                        ws_sent_count++;
                    #endif
                } else {
                    #if DebugCode
                        ws_blocked++;
                    #endif
                }
            }
        }
    }
}

// ================================================================
// TASK 3: GỬI LỆNH XUỐNG STM32 (CORE 1) - FIXED!
// ================================================================
void TaskUARTTransmitter(void *pvParameters) {
    TxPacket_t txOutPacket; // Buffer hứng dữ liệu từ Queue
    #if DebugCode
        DBG_LN("📤 UART TX Task started (Core 1)");
    #endif
    
    while (1) {
        // NHẬN SỬA ĐỔI: Nhận trực tiếp vào struct txOutPacket
        if (xQueueReceive(txQueue, &txOutPacket, pdMS_TO_TICKS(500)) == pdTRUE) {
            
            size_t sendSize = 0;
            uint8_t cmd = txOutPacket.cmdFrame.cmd; // Lấy cmd để xác định độ dài
            
            if (cmd == CMD_SET_TRAJECTORY) {
                sendSize = sizeof(TxConfigData_t); // 13 bytes
            } 
            else if(cmd == CMD_STATUS){
                sendSize = sizeof(TxStatusData_t);    // 5 bytes
            }
            else {
                sendSize = sizeof(TxCMDData_t);    // 4 bytes
            }
            
            // THỰC HIỆN GỬI: Sử dụng con trỏ tới vùng nhớ raw của Union
            size_t sent = STM32Serial.write(txOutPacket.raw, sendSize);
            
            // Ép UART đẩy dữ liệu đi ngay (tránh nằm trong buffer của ESP32)
            STM32Serial.flush(); 
            
            #if DebugCode
                uart_tx_count++;
                DBG("📤 Sent to STM32: Cmd=%d, Size=%d, Sent=%d\n", cmd, sendSize, sent);
                // In mã Hex để cậu debug xem có đúng AA BB không
                DBG("   HEX: ");
                for(int i=0; i<sendSize; i++) DBG("%02X ", txOutPacket.raw[i]);
                DBG("\n");
            #endif
        }
    }
}
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
void loop() {
    vTaskDelay(pdMS_TO_TICKS(1000));
}

void SendStatusToSTM32() {
    TxPacket_t packet;
    TxStatusData_t *pStatus = (TxStatusData_t*)packet.raw;

    pStatus->header[0]     = PROTOCOL_CMD_HEADER_1;
    pStatus->header[1]     = PROTOCOL_CMD_HEADER_2;
    pStatus->cmd           = CMD_STATUS;
    pStatus->wifi_status   = current_wifi_stat;
    pStatus->battery_status = current_bat_stat;
    pStatus->checksum      = CalculateChecksum(packet.raw, 5); // Checksum của 5 byte đầu

    xQueueSend(txQueue, &packet, 0);
}

void WiFiEvent(WiFiEvent_t event) {
    switch (event) {
        case ARDUINO_EVENT_WIFI_STA_CONNECTED:
        case ARDUINO_EVENT_WIFI_STA_GOT_IP:
            current_wifi_stat = WIFI_STATUS_CONNECTED;
            SendStatusToSTM32(); // Gửi ngay lệnh sáng đứng LED Vàng
            break;
        case ARDUINO_EVENT_WIFI_STA_DISCONNECTED:
            current_wifi_stat = WIFI_STATUS_CONNECTING;
            SendStatusToSTM32(); // Gửi ngay lệnh nháy LED Vàng
            break;
        default: break;
    }
}

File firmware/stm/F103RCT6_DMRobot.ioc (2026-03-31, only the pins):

Mcu.UserName=STM32F103RCTx
PA13.Signal=SYS_JTMS-SWDIO
PA14.Signal=SYS_JTCK-SWCLK
PA15.Signal=GPIO_Output
PA6.Signal=S_TIM3_CH1
PA7.Signal=S_TIM3_CH2
PA8.Signal=S_TIM1_CH1
PA9.Signal=S_TIM1_CH2
PB0.Signal=S_TIM3_CH3
PB1.Signal=S_TIM3_CH4
PB6.Signal=I2C1_SCL
PB7.Signal=I2C1_SDA
PC10.Signal=GPIO_Output
PC11.Signal=GPIO_Output
PC12.Signal=UART5_TX
PC6.Signal=S_TIM8_CH1
PC7.Signal=S_TIM8_CH2
PD0-OSC_IN.Signal=RCC_OSC_IN
PD1-OSC_OUT.Signal=RCC_OSC_OUT
PD2.Signal=UART5_RX

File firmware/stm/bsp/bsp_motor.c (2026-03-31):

/**
 * @file       bsp_motor.c
 * @copyright  [Your Copyright]
 * @license    [Your License]
 * @version    1.0.0
 * @date       2026-02-09
 * @author     Dong Son
 *
 * @brief
 */
/* Includes ----------------------------------------------------------- */
#include "bsp_motor.h"
#include "drv8871.h"
#include "err.h"

/* Private defines ---------------------------------------------------- */
#define BSP_MOTOR_CONVERSION_FACTOR	(2.0f * BSP_MOTOR_PI) / (BSP_MOTOR_ENCODER_PPR)
#define BSP_TIM_PWM_HANDLE 		htim3
#define BSP_TIM_ENCODERL_HANDLE htim1
#define BSP_TIM_ENCODERR_HANDLE htim8

/* Private enumerate/structure ---------------------------------------- */
typedef struct
{
	TIM_HandleTypeDef *pwm_tim;
	TIM_HandleTypeDef *encoder_tim;
	uint32_t pwm_channel[2];

	drv8871_t motor_driver;

	bsp_motor_data_t data;
} bsp_motor_t;
/* Private macros ----------------------------------------------------- */
/* Public variables --------------------------------------------------- */
extern TIM_HandleTypeDef BSP_TIM_PWM_HANDLE;
extern TIM_HandleTypeDef BSP_TIM_ENCODERL_HANDLE;
extern TIM_HandleTypeDef BSP_TIM_ENCODERR_HANDLE;

/* Private variables -------------------------------------------------- */
static bsp_motor_t motors[BSP_MOTOR_COUNT];

/* Private function prototypes ---------------------------------------- */
static inline void bsp_motor_get_counter(bsp_motor_id_t id);
static inline void bsp_motor_cal_vel(bsp_motor_id_t id, float dt);
static void motor_left_set_compare_channel1(uint16_t pwm);
static void motor_left_set_compare_channel2(uint16_t pwm);
static void motor_right_set_compare_channel1(uint16_t pwm);
static void motor_right_set_compare_channel2(uint16_t pwm);

/* Function definitions ----------------------------------------------- */
bsp_motor_err_t bsp_motor_init(void)
{
	bsp_motor_t *p_left 	= &motors[BSP_MOTOR_LEFT];
	p_left->pwm_tim         = &BSP_TIM_PWM_HANDLE;
	p_left->encoder_tim     = &BSP_TIM_ENCODERL_HANDLE;
	p_left->pwm_channel[0]  = TIM_CHANNEL_3;
	p_left->pwm_channel[1]  = TIM_CHANNEL_4;
	p_left->motor_driver.tim_set_compare_channel1 = motor_left_set_compare_channel1;
	p_left->motor_driver.tim_set_compare_channel2 = motor_left_set_compare_channel2;
	drv8871_init(&p_left->motor_driver);
	HAL_TIM_PWM_Start(p_left->pwm_tim, p_left->pwm_channel[0]);
	HAL_TIM_PWM_Start(p_left->pwm_tim, p_left->pwm_channel[1]);
	__HAL_TIM_SET_COMPARE(p_left->pwm_tim, p_left->pwm_channel[0], 0);
	__HAL_TIM_SET_COMPARE(p_left->pwm_tim, p_left->pwm_channel[1], 0);
	HAL_TIM_Encoder_Start(p_left->encoder_tim, TIM_CHANNEL_ALL);
	__HAL_TIM_SET_COUNTER(p_left->encoder_tim, 0);

	bsp_motor_t *p_right 	= &motors[BSP_MOTOR_RIGHT];
	p_right->pwm_tim        = &BSP_TIM_PWM_HANDLE;
	p_right->encoder_tim    = &BSP_TIM_ENCODERR_HANDLE;
	p_right->pwm_channel[0] = TIM_CHANNEL_2;
	p_right->pwm_channel[1] = TIM_CHANNEL_1;
	p_right->motor_driver.tim_set_compare_channel1 = motor_right_set_compare_channel1;
	p_right->motor_driver.tim_set_compare_channel2 = motor_right_set_compare_channel2;
	drv8871_init(&p_right->motor_driver);
	HAL_TIM_PWM_Start(p_right->pwm_tim, p_right->pwm_channel[0]);
	HAL_TIM_PWM_Start(p_right->pwm_tim, p_right->pwm_channel[1]);
	__HAL_TIM_SET_COMPARE(p_right->pwm_tim, p_right->pwm_channel[0], 0);
	__HAL_TIM_SET_COMPARE(p_right->pwm_tim, p_right->pwm_channel[1], 0);
	HAL_TIM_Encoder_Start(p_right->encoder_tim, TIM_CHANNEL_ALL);
	__HAL_TIM_SET_COUNTER(p_right->encoder_tim, 0);

	return BSP_MOTOR_OK;
}

bsp_motor_err_t bsp_motor_find_params(void)
{
	bsp_motor_init();
	bsp_motor_t *p_left 	= &motors[BSP_MOTOR_LEFT];
	bsp_motor_t *p_right 	= &motors[BSP_MOTOR_RIGHT];
	__HAL_TIM_SET_COMPARE(p_left->pwm_tim, p_left->pwm_channel[0], __HAL_TIM_GET_AUTORELOAD(p_left->pwm_tim));
	__HAL_TIM_SET_COMPARE(p_right->pwm_tim, p_right->pwm_channel[0], __HAL_TIM_GET_AUTORELOAD(p_right->pwm_tim));

	return BSP_MOTOR_OK;
}

bsp_motor_err_t bsp_motor_get_data(bsp_motor_id_t id, bsp_motor_data_t *p_data_out, float dt)
{
     CHECK_PARAM((id >= BSP_MOTOR_COUNT || p_data_out != NULL), BSP_MOTOR_ERR_PARAM);

     bsp_motor_cal_vel(id, dt);

     *p_data_out = motors[id].data;

     return BSP_MOTOR_OK;
}

bsp_motor_err_t bsp_motor_get_data_kinematics(bsp_motor_id_t id, float dt, float *omega, float *d)
{
     CHECK_PARAM((id >= BSP_MOTOR_COUNT ), BSP_MOTOR_ERR_PARAM);

     bsp_motor_cal_vel(id, dt);

     *omega = motors[id].data.cur_omega;
     *d		= motors[id].data.d;

     return BSP_MOTOR_OK;
}

float bsp_motor_get_vel(bsp_motor_id_t id, float dt)
{
	bsp_motor_cal_vel(id, dt);
	return motors[id].data.cur_omega;
}

float bsp_motor_get_round(bsp_motor_id_t id, float dt)
{
	bsp_motor_cal_vel(id, dt);
	return motors[id].data.cntPos * 360.0f;
}

bsp_motor_err_t bsp_motor_set_vel(bsp_motor_id_t id, int16_t pwm)
{
	CHECK_PARAM((id >= BSP_MOTOR_COUNT), BSP_MOTOR_ERR_PARAM);

	drv8871_set_pwm(&motors[id].motor_driver, pwm);

	return BSP_MOTOR_OK;
}

bsp_motor_err_t bsp_motor_stop(void)
{
	bsp_motor_t *p_left 	= &motors[BSP_MOTOR_LEFT];
	bsp_motor_t *p_right 	= &motors[BSP_MOTOR_RIGHT];
	__HAL_TIM_SET_COMPARE(p_left->pwm_tim, p_left->pwm_channel[0], 0);
	__HAL_TIM_SET_COMPARE(p_left->pwm_tim, p_left->pwm_channel[1], 0);
	__HAL_TIM_SET_COMPARE(p_right->pwm_tim, p_right->pwm_channel[0], 0);
	__HAL_TIM_SET_COMPARE(p_right->pwm_tim, p_right->pwm_channel[1], 0);
	return BSP_MOTOR_OK;
}

/* Private definitions ------------------------------------------------ */
static inline void bsp_motor_get_counter(bsp_motor_id_t id)
{
	uint16_t currentCounter = (uint16_t)__HAL_TIM_GET_COUNTER(motors[id].encoder_tim);

	int16_t delta = (int16_t)(currentCounter - motors[id].data.lastCounterVal);

	motors[id].data.totalTicks += delta;

	motors[id].data.cntVel = delta;

	motors[id].data.d = (float)delta*(float)BSP_WHEEL_TRACK;

	motors[id].data.total_distance += motors[id].data.d;

	if (BSP_MOTOR_ENCODER_PPR > 0)
	{
		motors[id].data.cntPos = (float)motors[id].data.totalTicks / (float)BSP_MOTOR_ENCODER_PPR;
	}

	motors[id].data.lastCounterVal = currentCounter;
}

static inline void bsp_motor_cal_vel(bsp_motor_id_t id, float dt)
{
	bsp_motor_get_counter(id);

	if (dt > 0.0001f)
	{
		motors[id].data.cur_omega = (motors[id].data.cntVel * BSP_MOTOR_CONVERSION_FACTOR) / dt;
	}
	else
	{
		motors[id].data.cur_omega = 0.0f;
	}
}

static void motor_left_set_compare_channel1(uint16_t pwm)
{
	__HAL_TIM_SET_COMPARE(motors[BSP_MOTOR_LEFT].pwm_tim, motors[BSP_MOTOR_LEFT].pwm_channel[0], pwm);
}

static void motor_left_set_compare_channel2(uint16_t pwm)
{
	__HAL_TIM_SET_COMPARE(motors[BSP_MOTOR_LEFT].pwm_tim, motors[BSP_MOTOR_LEFT].pwm_channel[1], pwm);
}

static void motor_right_set_compare_channel1(uint16_t pwm)
{
	__HAL_TIM_SET_COMPARE(motors[BSP_MOTOR_RIGHT].pwm_tim, motors[BSP_MOTOR_RIGHT].pwm_channel[0], pwm);
}

static void motor_right_set_compare_channel2(uint16_t pwm)
{
	__HAL_TIM_SET_COMPARE(motors[BSP_MOTOR_RIGHT].pwm_tim, motors[BSP_MOTOR_RIGHT].pwm_channel[1], pwm);
}
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

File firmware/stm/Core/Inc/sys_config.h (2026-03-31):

 /**
 * @file       sys_config.h
 * @copyright  [Your Copyright]
 * @license    [Your License]
 * @version    1.0.0
 * @date       2026-02-09
 * @author     Dong Son
 *
 * @brief
 */
/* Define to prevent recursive inclusion ------------------------------ */
#ifndef INC_SYS_CONFIG_H_
#define INC_SYS_CONFIG_H_

/* Includes ----------------------------------------------------------- */
#include <stdint.h>

/* Public defines ----------------------------------------------------- */
// Kinematics
#define USE_FEEDBACK_LINEARIZATION	0
#define LOOK_AHEAD_DIST				0.05f
#define MAX_PATH_POINTS				500u
#define WHEEL_RADIUS				0.0344f
#define WHEEL_BASE					0.2f
#define KV 							6.0f
#define KW 							10.0f
#define SAFETY_FACTOR 				0.95f
#define PI							3.14159265358979323846f
#define USE_ODOMETRY				true
// Controller
#define PID_MAX_OUTPUT 				1000.0f
// Motor
#define MOTOR_MAX_OMEGA				12.0f
#define MOTOR_ENCODER_PPR			1980u	// x4
#define MOTOR_COUNT 				2
#define WHEEL_TRACK_FACTOR			(2.0f * PI * WHEEL_RADIUS) / MOTOR_ENCODER_PPR

/* Public enumerate/structure ----------------------------------------- */
typedef enum
{
	STREAM_CIRCLE = 0,
	STREAM_SQUARE,
	STREAM_TRIANGLE,
	STREAM_FIGURE8,
	STREAM_PATH,
} stream_trajectory_shape_t;

typedef enum
{
	STREAM_WIFI_CONNECTING = 0x00,
	STREAM_WIFI_CONNECTED  = 0x01,
} stream_wifi_status_t;

typedef enum
{
	STREAM_BATTERY_HIGH = 0x00,
	STREAM_BATTERY_MID  = 0x01,
	STREAM_BATTERY_LOW  = 0x02,
} stream_battery_status_t;

typedef enum
{
    STREAM_CMD_STOP = 0,
	STREAM_CMD_RUN,
	STREAM_CMD_RETURN_HOME,
	STREAM_CMD_SET_TRAJECTORY,
	STREAM_CMD_SET_PATH,
	STREAM_CMD_STATUS,
	STREAM_CMD_NONE
} stream_cmd_t;

typedef enum
{
	STREAM_STOP = 0,
	STREAM_RUN,
	STREAM_RETURN_HOME,
	STREAM_CONFIG,
	STREAM_NONE,
} stream_state_t;

#pragma pack(1)
typedef struct
{
    uint8_t header[2];
    uint8_t cmd;
    uint8_t shape;
    float 	param;
    float 	velocity;
    uint8_t checksum;
} stream_rx_trajectory_config_t;

typedef struct
{
    uint8_t header[2];
    uint8_t cmd;
    uint8_t wifi_status;
    uint8_t battery_status;
    uint8_t checksum;
} stream_rx_status_t;

typedef struct
{
    uint8_t 	header[2];
    uint8_t 	cmd;
    uint16_t 	count;
	float 		velocity;
    uint8_t 	is_cycle;
    float 		start_x;
    float 		start_y;
} stream_rx_path_config_t;

typedef struct
{
	float Pdx;
	float Pdy;
	float Px;
	float Py;
	float V;
	float W;
	float Ex;
	float Ey;
	float Etheta;
} stream_tx_data_t;
#pragma pack()

/* Public macros ------------------------------------------------------ */
/* Public variables --------------------------------------------------- */
/* Public function prototypes ----------------------------------------- */

#endif /* INC_SYS_CONFIG_H_ */

/* End of file -------------------------------------------------------- */
